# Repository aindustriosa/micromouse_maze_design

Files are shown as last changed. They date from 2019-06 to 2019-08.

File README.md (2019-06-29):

# Diseño de un laberinto para pruebas de micromouse.
NOTA: Este diseño se está probando todavía. Tomad todas las medidas con un espítiu crítico ;-)

Este repositorio contiene los planos para construir un laberinto reconfigurable para pruebas de micromouse. El diseño está adaptado para la normativa de las competiciones como la OSWHDEM (http://rules.oshwdem.org/labirinto_es) o la de Open Robosports (https://github.com/open-robosports/normativa-laberinto).

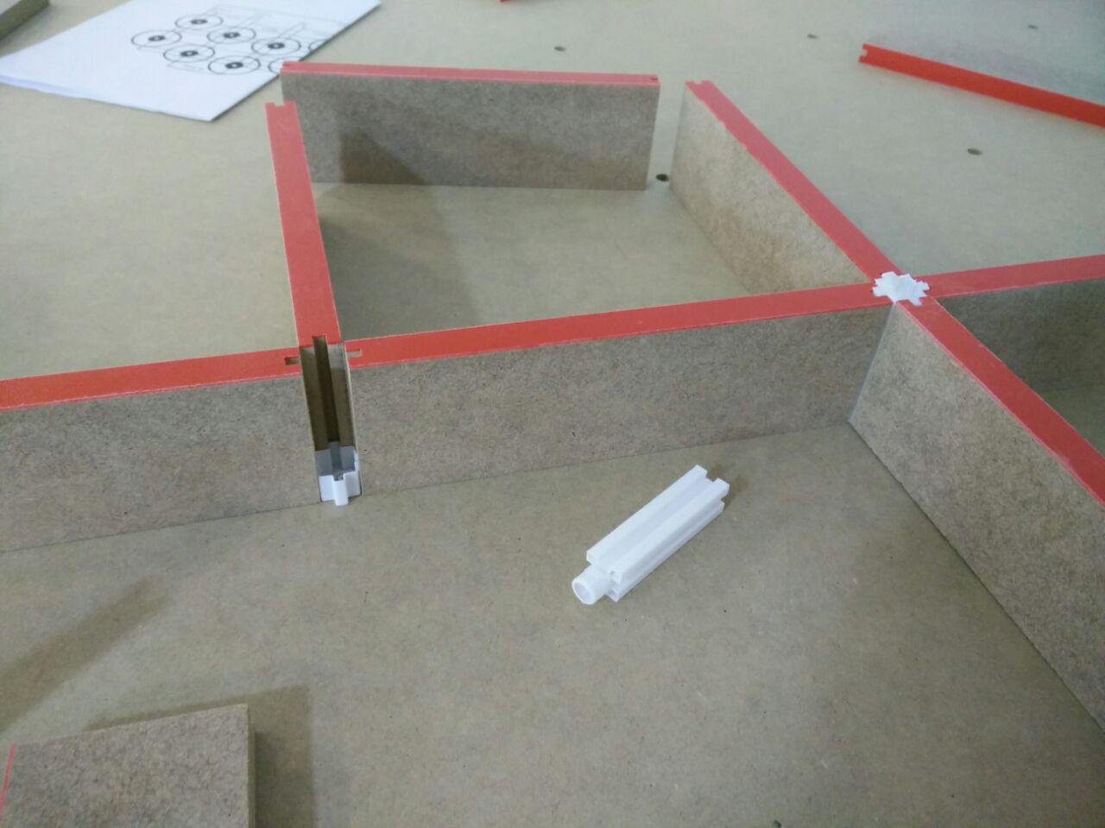
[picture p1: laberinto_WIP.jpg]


El laberinto es modular, la base se divide en 3x3 paneles.

Tanto la base como las paredes están hechas en madera. El diseño de las mismas está en el directorio ./wooden_base_walls

Los postes que soportan las paredes están impresos en 3D. El diseño (Freecad + STLs) está en el directorio ./poles_3d_design

# Ya tengo las piezas... cómo hago el laberinto?
Para diseñar el mapa de un laberinto, se puede usar un software como:
- https://github.com/brico-labs/OshwdemMazes/tree/master/src/MazeGenerator

También puedes utilizar buenos mapas hechos por otros:
- https://github.com/micromouseonline/mazefiles
- http://www.tcp4me.com/mmr/mazes/

# Otras referencias
- http://www.micromouseonline.com/micromouse-book/mazes-and-maze-solving/construction/

# Agradecimientos
Gracias a Bulebots (https://github.com/Bulebots) por la inspiración y algunas de las referencias de este README.

Gracias a nuestro carpintero de confianza ;-D, Suso.

# TODO
- Diseños 3D de base y paredes.
- Probar laberinto de 1X2 paneles.

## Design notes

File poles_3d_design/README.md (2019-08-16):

# Postes impresos en 3D

En este directorio se pueden encontrar los ficheros de diseño y STLs de los diferentes tipos de postes empleados.

Los postes están fijados a la base y aguantan las paredes. Hay postes con distintos números de ranuras para acomodar esquinas donde confluyen uno, dos, tres o cuatro paredes.

Los postes se han diseñado usando Freecad. Antes de imprimir, revisar la tolerancia de los agujeros en la base para adecuar la pieza. Puede que sean necesarios un par de intentos para ajustar el valor del radio del cilindro en el poste.

Los postes con la palabra "recortado" en el nombre tienen un rebaje de 1mm en la cara donde tiene ranura. Estos postes se puden usar para controlar los errores acumulados al montar el laberinto.

Para imprimir los postes, se han usado las siguientes especificaciones:

- PLA blanco
- 1 pared
- Infill de 5%

El fichero anet_A8_6_postes.gcode funciona correctamente con la impresora Anet A8 del local de A Industriosa.

Los ficheros con nombre "Prusa" están optimizados para una Prusa MK3.

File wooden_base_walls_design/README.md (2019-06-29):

# Base y paredes hechas en madera.

El diseño es el de la siguiente imagen.

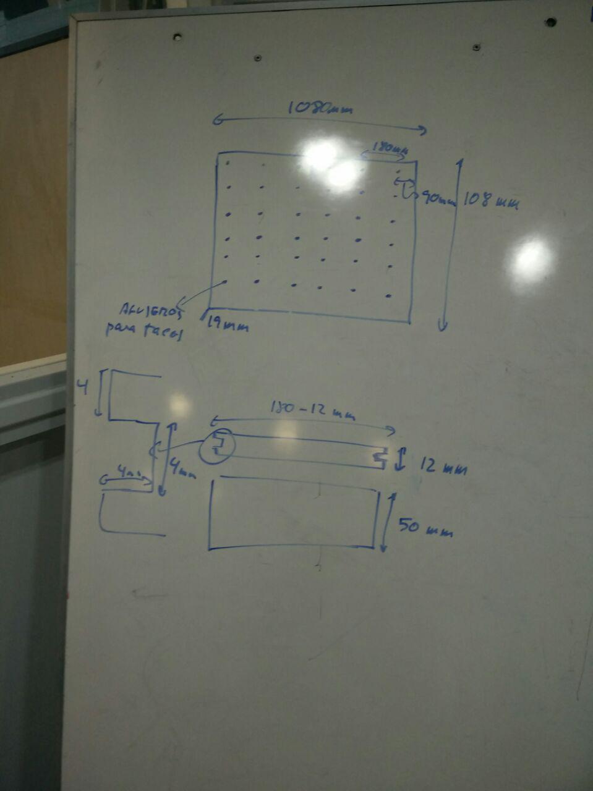
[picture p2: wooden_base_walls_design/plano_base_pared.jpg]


Por un lado, se divide el laberinto original (3x3 metros) en 9 cuadrados.

Por otro lado, las paredes tienen una ranura para encajar en los postes.

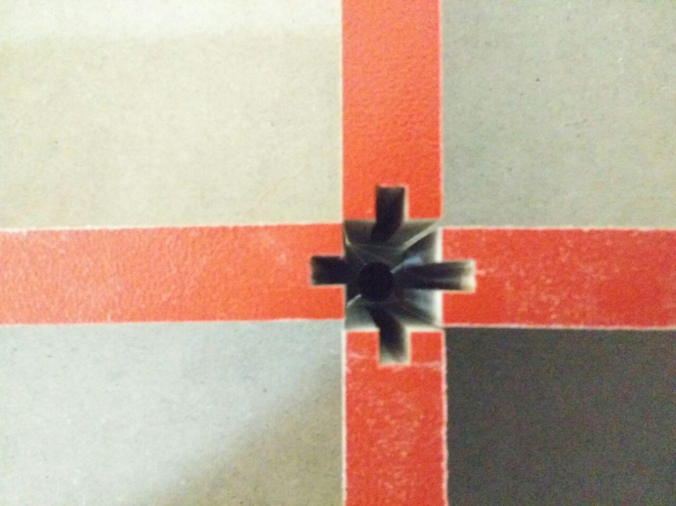
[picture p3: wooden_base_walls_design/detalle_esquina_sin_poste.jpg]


La base y las paredes se han hecho en madera DM.

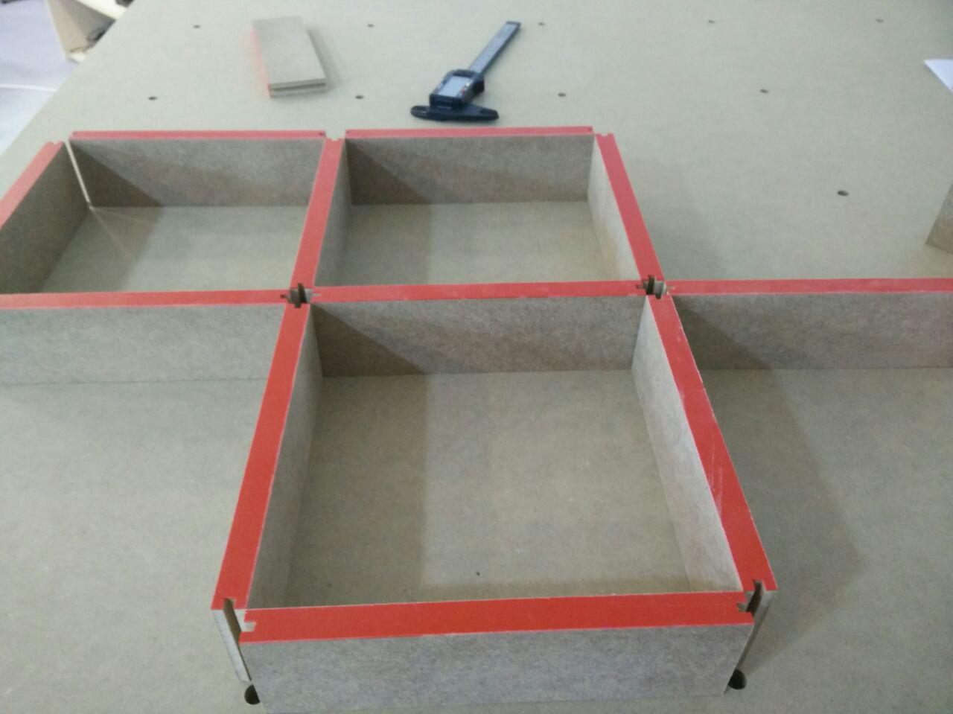
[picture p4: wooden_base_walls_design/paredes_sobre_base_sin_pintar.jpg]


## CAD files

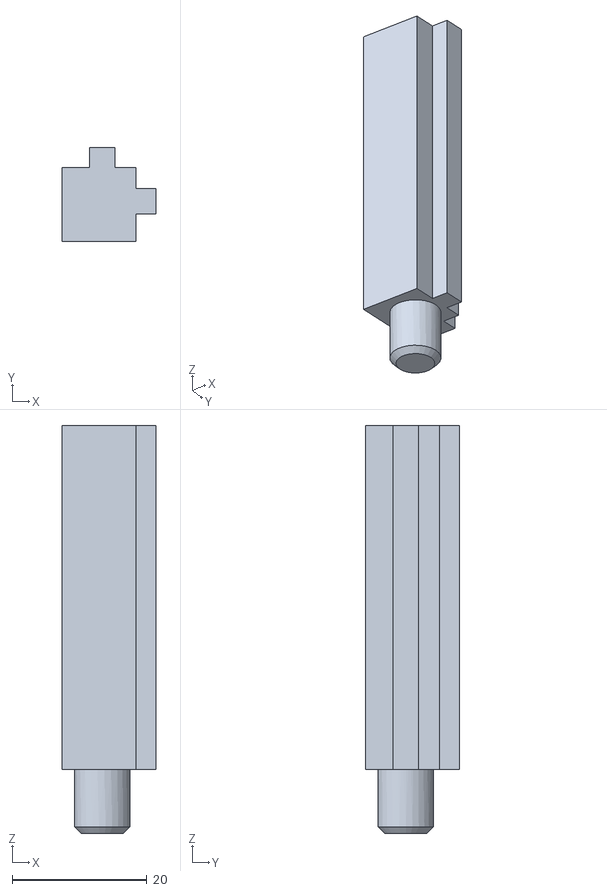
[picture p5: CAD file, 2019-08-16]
poles_3d_design/Prusa_poste_recortado_2_paredes_esquina.stl
14.0 x 14.0 x 60.5

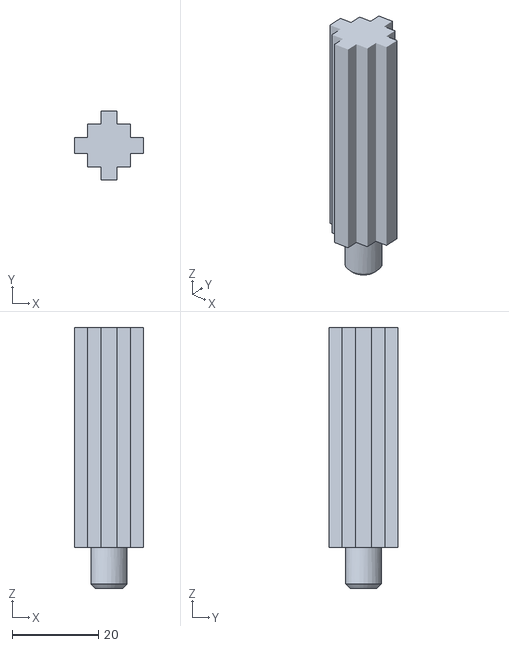
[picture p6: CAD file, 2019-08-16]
poles_3d_design/Prusa_poste_recortado_4_paredes.stl
16.0 x 16.0 x 60.5

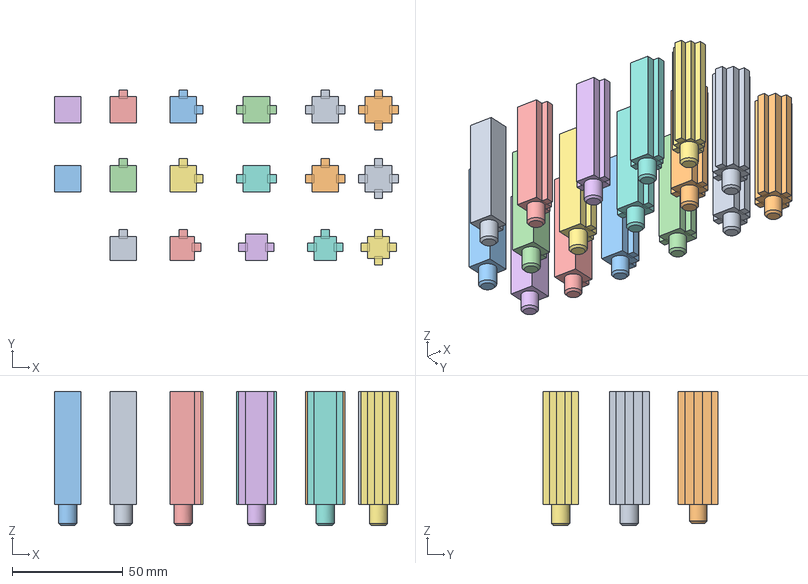
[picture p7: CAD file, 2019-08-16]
poles_3d_design/poste.FCStd
155.0 x 79.0 x 60.5 mm
A8_poste_3_paredes
A8_poste_4_paredes
A8_poste_2_paredes_esquina
A8_poste_2_paredes_linea
A8_poste_1_pared
A8_poste_0_pared
Prusa_poste_2_paredes_esquina
Prusa_poste_2_paredes_linea
Prusa_poste_4_paredes
Prusa_poste_3_paredes
Prusa_poste_0_pared
Prusa_poste_1_pared
Prusa_poste_recortado_2_paredes_esquina
Prusa_poste_recortado_2_paredes_linea
Prusa_poste_recortado_4_paredes
Prusa_poste_recortado_3_paredes
Prusa_poste_recortado_1_pared

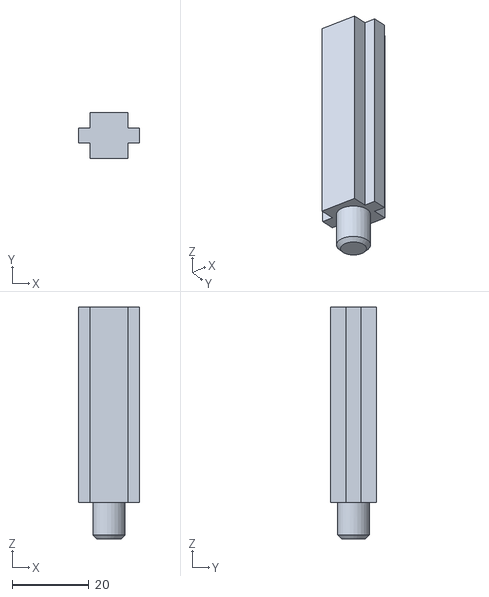
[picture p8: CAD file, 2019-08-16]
poles_3d_design/Prusa_poste_recortado_2_paredes_linea.stl
16.0 x 12.0 x 60.5

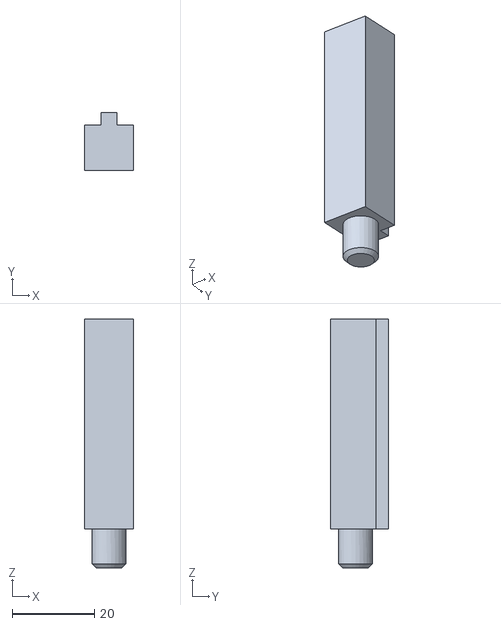
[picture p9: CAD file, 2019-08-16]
poles_3d_design/Prusa_poste_recortado_1_pared.stl
12.0 x 14.0 x 60.5

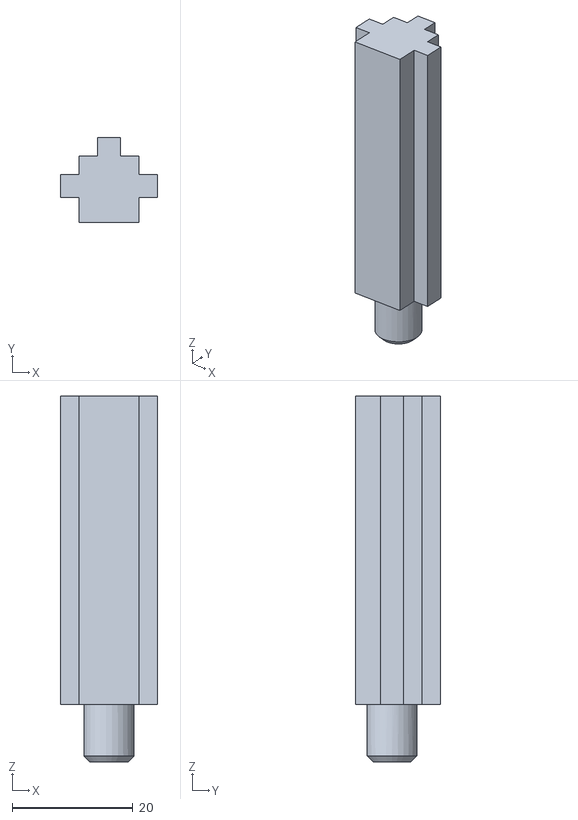
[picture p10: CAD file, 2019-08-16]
poles_3d_design/Prusa_poste_recortado_3_paredes.stl
16.0 x 14.0 x 60.5

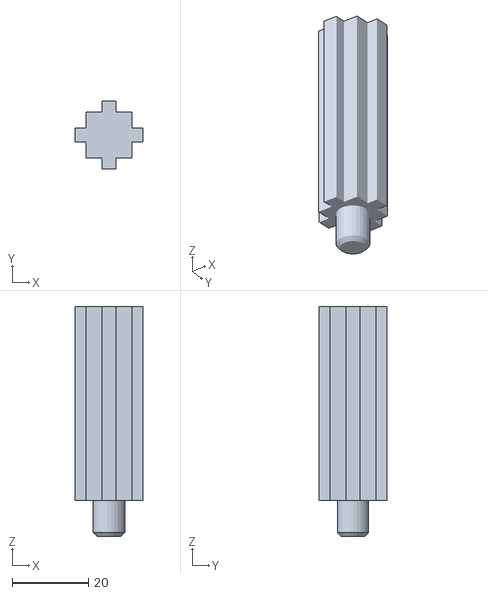
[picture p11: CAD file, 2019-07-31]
poles_3d_design/Prusa_poste_4_paredes.stl
18.0 x 18.0 x 60.5

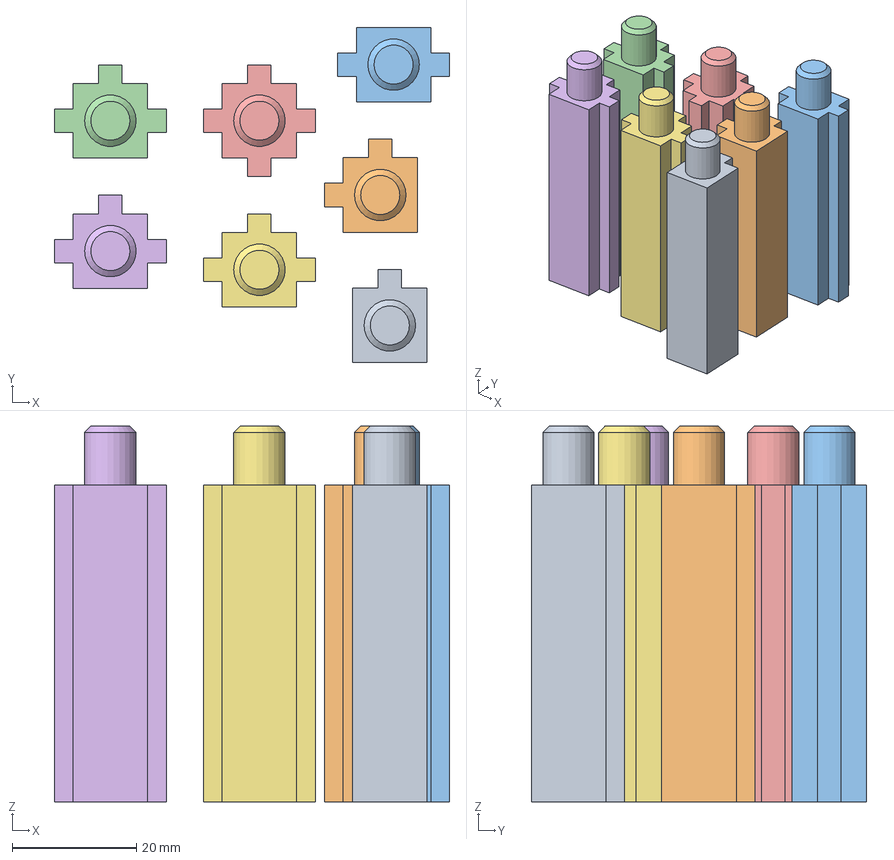
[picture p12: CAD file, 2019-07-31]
poles_3d_design/Prusa_6_postes.3mf
63.6 x 54.0 x 60.5 mm
Prusa_poste_1_pared.stl
Prusa_poste_2_paredes_esquina.stl
Prusa_poste_2_paredes_linea.stl
Prusa_poste_3_paredes.stl x 3
Prusa_poste_4_paredes.stl

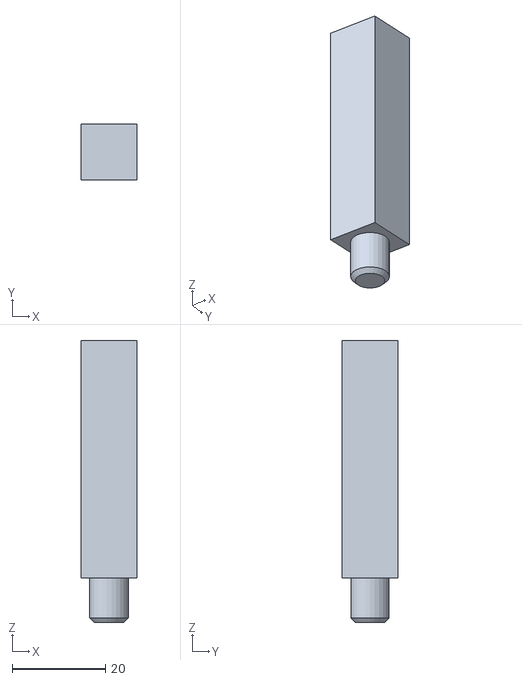
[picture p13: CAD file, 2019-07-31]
poles_3d_design/Prusa_poste_0_pared.stl
12.0 x 12.0 x 60.5

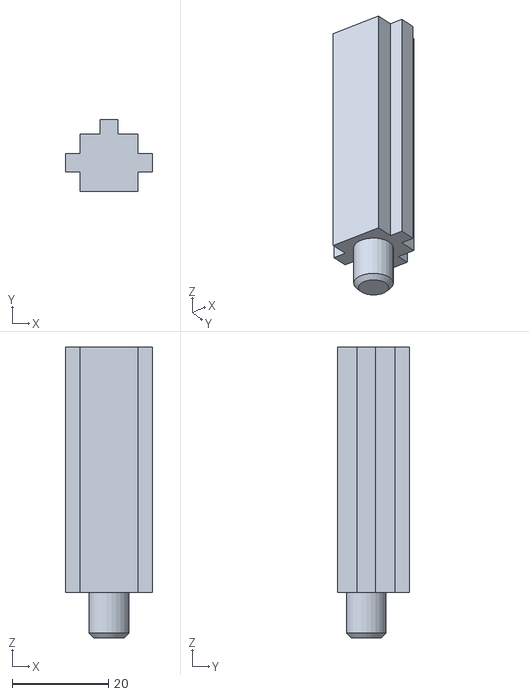
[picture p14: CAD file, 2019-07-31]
poles_3d_design/Prusa_poste_3_paredes.stl
18.0 x 15.0 x 60.5

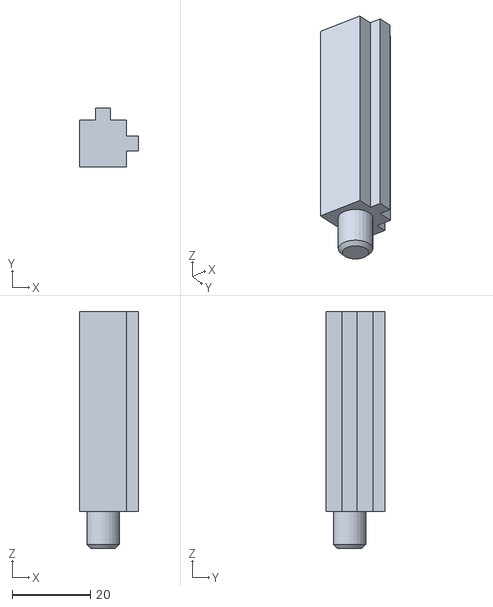
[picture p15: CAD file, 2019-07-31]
poles_3d_design/Prusa_poste_2_paredes_esquina.stl
15.0 x 15.0 x 60.5

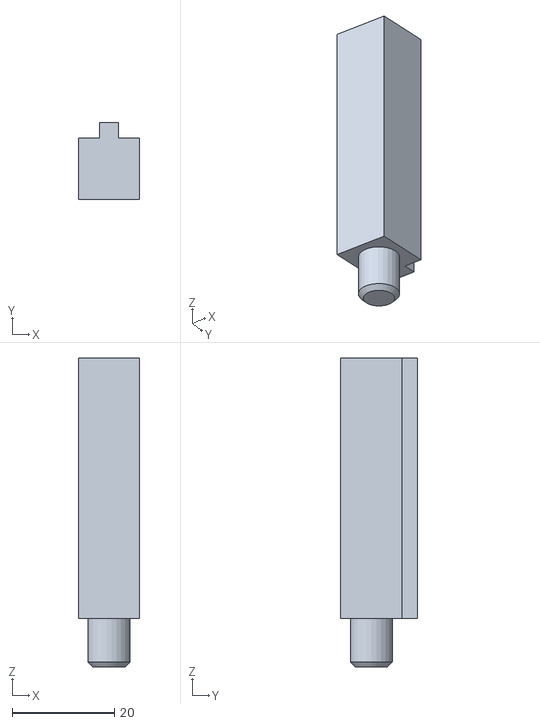
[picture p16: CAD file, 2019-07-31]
poles_3d_design/Prusa_poste_1_pared.stl
12.0 x 15.0 x 60.5

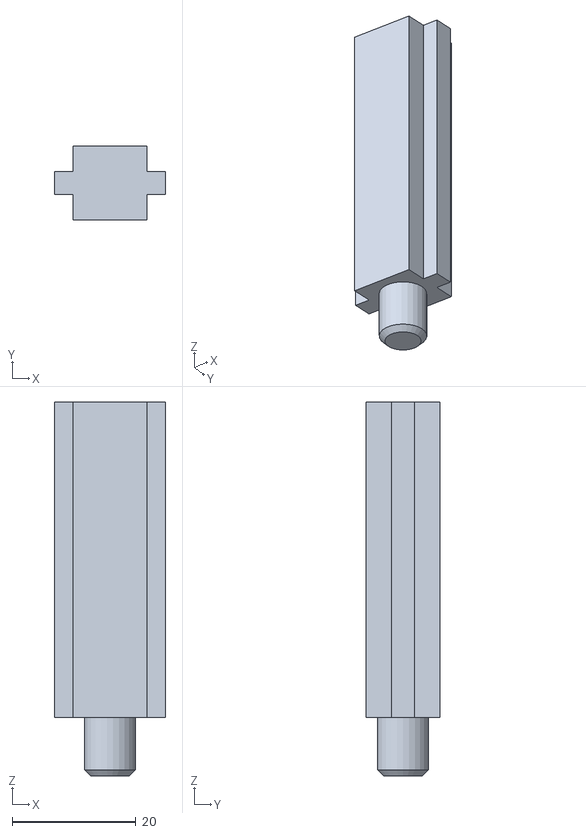
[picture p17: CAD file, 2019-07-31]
poles_3d_design/Prusa_poste_2_paredes_linea.stl
18.0 x 12.0 x 60.5

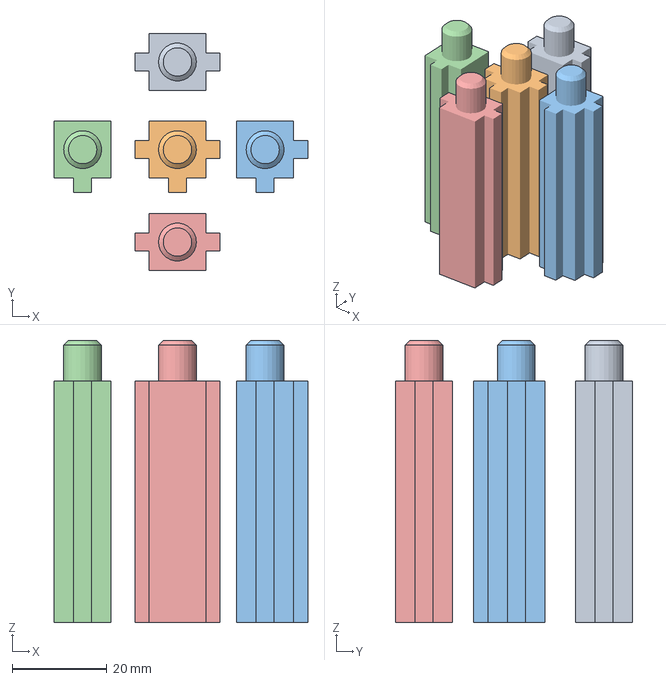
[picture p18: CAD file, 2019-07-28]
poles_3d_design/5_postes.3mf
53.5 x 50.0 x 59.5 mm

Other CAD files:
poles_3d_design/A8_poste_0_pared.stl
poles_3d_design/A8_poste_1_pared.stl
poles_3d_design/A8_poste_4_paredes.stl
poles_3d_design/A8_poste_2_paredes_linea.stl
poles_3d_design/A8_poste_2_paredes_esquina.stl
poles_3d_design/A8_poste_3_paredes.stl

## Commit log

2019-06-29 Design initial files
    [poste.FCStd, poste_2_paredes_esquina.stl, poste_2_paredes_linea.stl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]
2019-06-29 Updated READMEs and add pole for a single wall
    [poste.FCStd, poste_1_pared.stl]
2019-06-29 Add gcode for printing 6 poles
2019-07-25 Add zero slots post
    [poste.FCStd, poste_0_pared.stl]
2019-07-28 Add configuration for prusa printer
    [5_postes.3mf, A8_poste_0_pared.stl, A8_poste_1_pared.stl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]
2019-07-31 Update Prusa version of poles
    [Prusa_6_postes.3mf, Prusa_poste_0_pared.stl, Prusa_poste_1_pared.stl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]
2019-08-16 Add thinner poles set.
    [Prusa_poste_recortado_1_pared.stl, Prusa_poste_recortado_2_paredes_esquina.stl, Prusa_poste_recortado_2_paredes_linea.stl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]
